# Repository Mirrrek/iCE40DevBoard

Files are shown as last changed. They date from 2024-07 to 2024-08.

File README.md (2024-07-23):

# iCE40 DevBoard

This project was made as part of [Hack Club Arcade 2024](https://hackclub.com/arcade/).

## Warning

The current board design has not been tested and has known mistakes:
1. **R3 is placed on the wrong side of the level shifter.** Do not solder R3 on and add a 1k pullup to 3v3 on the FPGA's _CDONE_ pin (via TP4).
2. **The FPGA's _SPI\_SS_ pin is missing a pullup resistor.** Add a 10k pullup to 3v3 on the FPGA's _SPI\_SS_ pin (via TP9).

These changes will be permanently applied to the design in a future iteration.

## Hardware

All required libraries can be downloaded from [SnapEDA](https://www.snapeda.com/home/).

- **iCE5LP2K-SG48ITR** FPGA
- **10118194-0011LF** USB micro connector
- **AMS1117** 3.3V and 1.2V voltage regulators
- **AT25DN011** SPI flash
- **CCBTLV3257MPWREP** multiplexer
- **TXS0108EPWR** level shifter

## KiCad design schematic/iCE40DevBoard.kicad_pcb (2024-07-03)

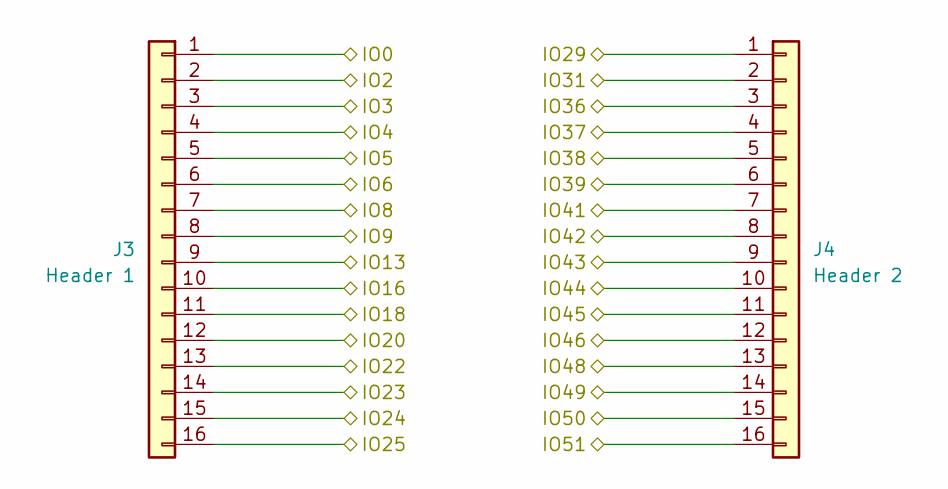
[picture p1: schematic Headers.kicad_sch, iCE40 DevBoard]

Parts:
J3: Header 1; PinHeader_1x16_P2.54mm_Vertical
J4: Header 2; PinHeader_1x16_P2.54mm_Vertical

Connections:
/FPGA/IO0: J3.1; also elsewhere on the board
/FPGA/IO2: J3.2; also elsewhere on the board
/FPGA/IO3: J3.3; also elsewhere on the board
/FPGA/IO4: J3.4; also elsewhere on the board
/FPGA/IO5: J3.5; also elsewhere on the board
/FPGA/IO6: J3.6; also elsewhere on the board
/FPGA/IO8: J3.7; also elsewhere on the board
/FPGA/IO9: J3.8; also elsewhere on the board
/FPGA/IO13: J3.9; also elsewhere on the board
/FPGA/IO16: J3.10; also elsewhere on the board
/FPGA/IO18: J3.11; also elsewhere on the board
/FPGA/IO20: J3.12; also elsewhere on the board
/FPGA/IO22: J3.13; also elsewhere on the board
/FPGA/IO23: J3.14; also elsewhere on the board
/FPGA/IO24: J3.15; also elsewhere on the board
/FPGA/IO25: J3.16; also elsewhere on the board
/FPGA/IO29: J4.1; also elsewhere on the board
/FPGA/IO31: J4.2; also elsewhere on the board
/FPGA/IO36: J4.3; also elsewhere on the board
/FPGA/IO37: J4.4; also elsewhere on the board
/FPGA/IO38: J4.5; also elsewhere on the board
/FPGA/IO39: J4.6; also elsewhere on the board
/FPGA/IO41: J4.7; also elsewhere on the board
/FPGA/IO42: J4.8; also elsewhere on the board
/FPGA/IO43: J4.9; also elsewhere on the board
/FPGA/IO44: J4.10; also elsewhere on the board
/FPGA/IO45: J4.11; also elsewhere on the board
/FPGA/IO46: J4.12; also elsewhere on the board
/FPGA/IO48: J4.13; also elsewhere on the board
/FPGA/IO49: J4.14; also elsewhere on the board
/FPGA/IO50: J4.15; also elsewhere on the board
/FPGA/IO51: J4.16; also elsewhere on the board

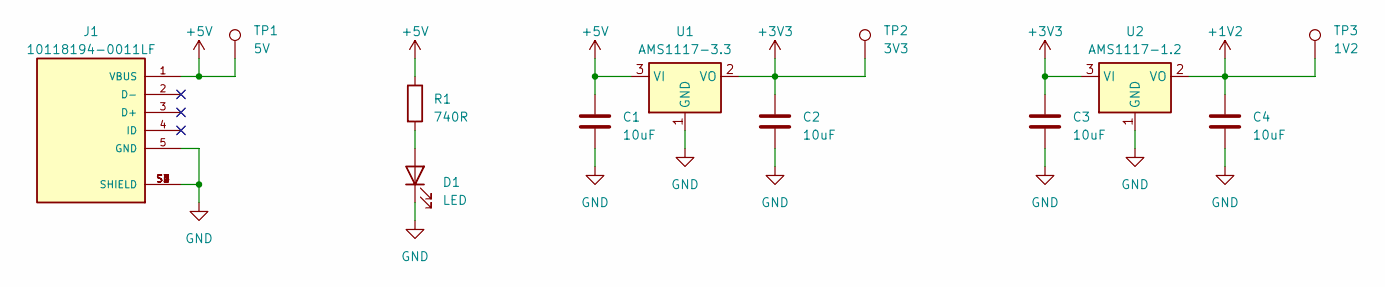
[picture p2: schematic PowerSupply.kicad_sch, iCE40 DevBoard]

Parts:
C1, C2, C3, C4: 10uF; C_0603_1608Metric
D1: LED; LED_0805_2012Metric
J1: 10118194-0011LF; AMPHENOL_10118194-0011LF; PARTREV D
R1: 740R; R_0603_1608Metric
TP1: 5V; TestPoint_Pad_D1.0mm
TP2: 3V3; TestPoint_Pad_D1.0mm
TP3: 1V2; TestPoint_Pad_D1.0mm
U1: AMS1117-3.3; SOT-223-3_TabPin2
U2: AMS1117-1.2; SOT-223-3_TabPin2

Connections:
+1V2: C4.1, TP3.1, U2.2 (VO); also elsewhere on the board
+3V3: C2.1, C3.1, TP2.1, U1.2 (VO), U2.3 (VI); also elsewhere on the board
+5V: C1.1, J1.1 (VBUS), R1.1, TP1.1, U1.3 (VI); also elsewhere on the board
GND: C1.2, C2.2, C3.2, C4.2, D1.1 (K), J1.5 (GND), J1.S1 (SHIELD), J1.S2 (SHIELD), J1.S3 (SHIELD), J1.S4 (SHIELD), J1.S5 (SHIELD), J1.S6 (SHIELD), U1.1 (GND), U2.1 (GND); also elsewhere on the board
unnamed: D1.2 (A), R1.2

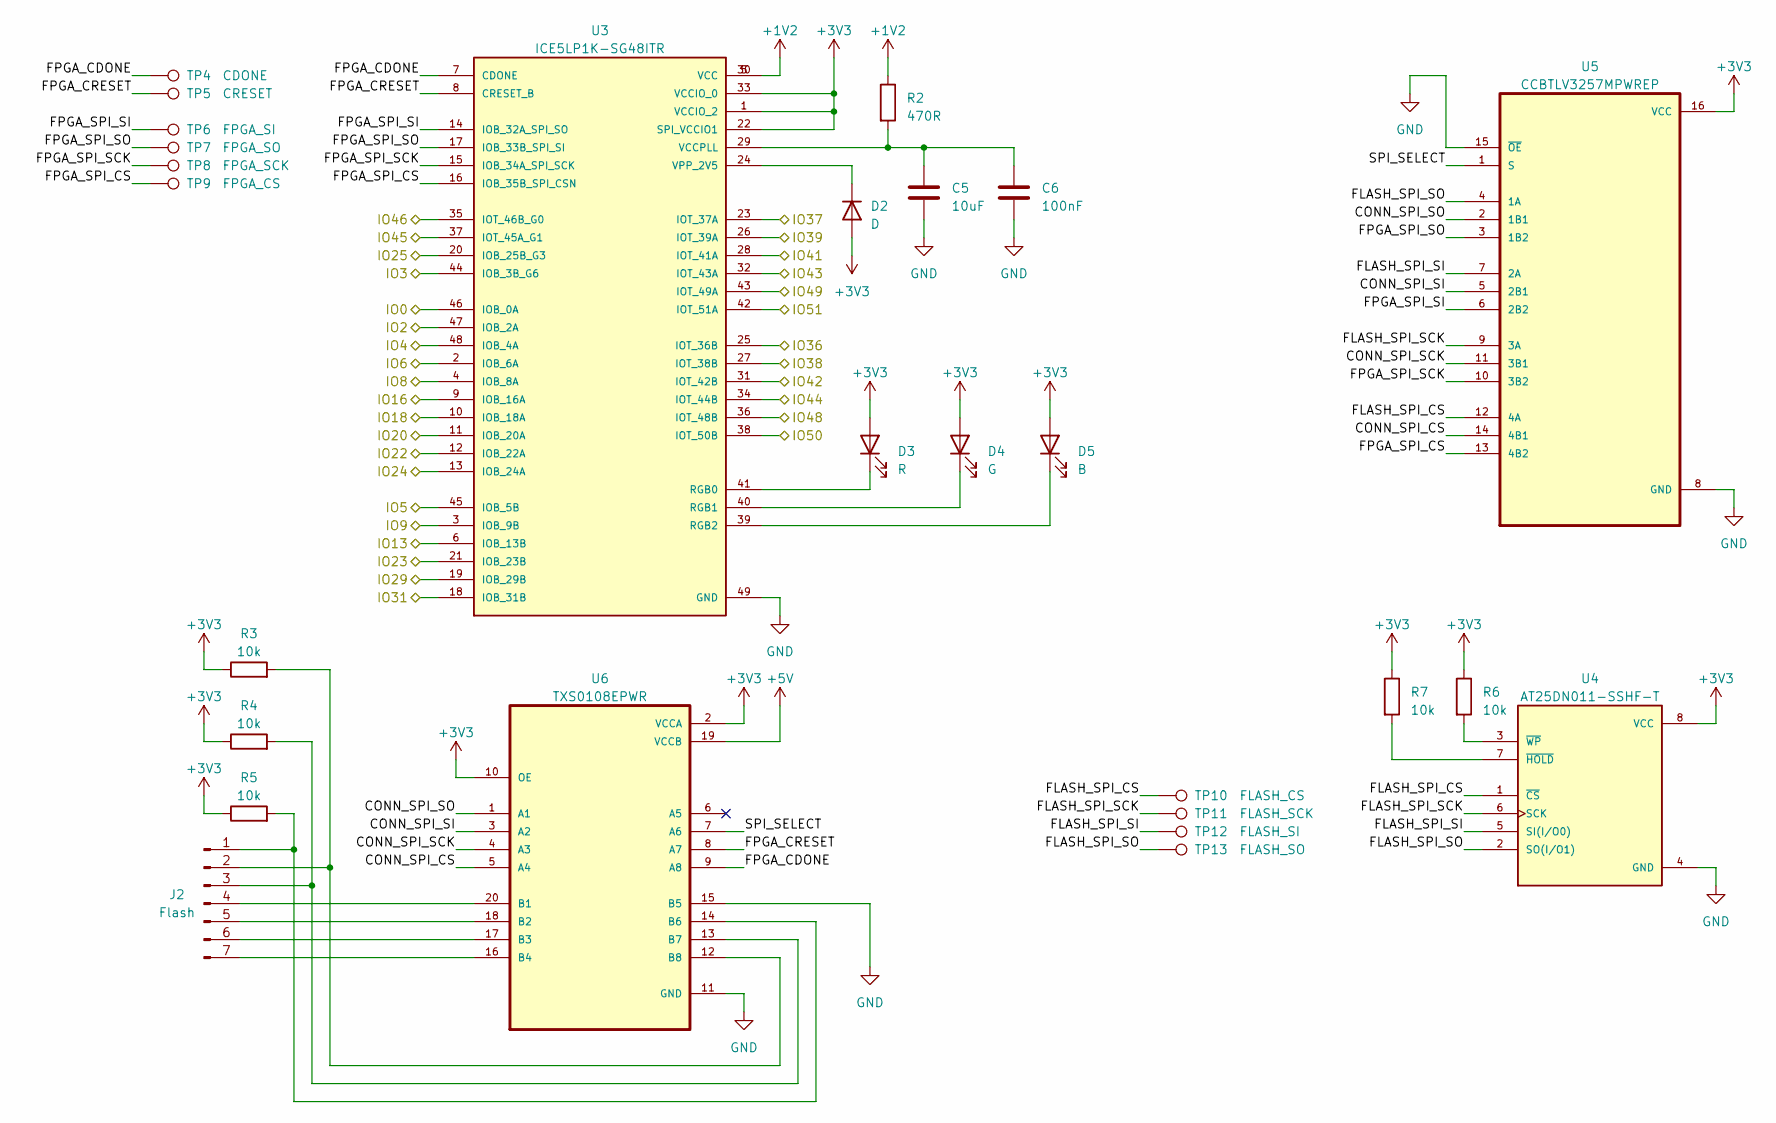
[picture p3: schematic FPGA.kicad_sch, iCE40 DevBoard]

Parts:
C5: 10uF; C_0603_1608Metric
C6: 100nF; C_0603_1608Metric
D2: D; D_0603_1608Metric
D3: R; LED_0805_2012Metric
D4: G; LED_0805_2012Metric
D5: B; LED_0805_2012Metric
J2: Flash; PinHeader_1x07_P2.54mm_Vertical
R2: 470R; R_0603_1608Metric
R3, R4, R5, R6, R7: 10k; R_0603_1608Metric
TP4: CDONE; TestPoint_Pad_D1.0mm
TP5: CRESET; TestPoint_Pad_D1.0mm
TP6: FPGA_SI; TestPoint_Pad_D1.0mm
TP7: FPGA_SO; TestPoint_Pad_D1.0mm
TP8: FPGA_SCK; TestPoint_Pad_D1.0mm
TP9: FPGA_CS; TestPoint_Pad_D1.0mm
TP10: FLASH_CS; TestPoint_Pad_D1.0mm
TP11: FLASH_SCK; TestPoint_Pad_D1.0mm
TP12: FLASH_SI; TestPoint_Pad_D1.0mm
TP13: FLASH_SO; TestPoint_Pad_D1.0mm
U3: ICE5LP1K-SG48ITR; QFN50P700X700X100-49N
U4: AT25DN011-SSHF-T; SOIC127P599X175-8N; PARTREV G
U5: CCBTLV3257MPWREP; SOP65P640X120-16N
U6: TXS0108EPWR; SOP65P640X120-20N

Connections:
+1V2: R2.1, U3.5 (VCC), U3.30 (VCC); also elsewhere on the board
+3V3: D2.2 (A), D3.2 (A), D4.2 (A), D5.2 (A), R3.1, R4.1, R5.1, R6.1, R7.1, U3.1 (VCCIO_2), U3.22 (SPI_VCCIO1), U3.33 (VCCIO_0), U4.8 (VCC), U5.16 (VCC), U6.2 (VCCA), U6.10 (OE); also elsewhere on the board
+5V: U6.19 (VCCB); also elsewhere on the board
/FPGA/CONN_SPI_CS: U5.14 (4B1), U6.5 (A4)
/FPGA/CONN_SPI_SCK: U5.11 (3B1), U6.4 (A3)
/FPGA/CONN_SPI_SI: U5.5 (2B1), U6.3 (A2)
/FPGA/CONN_SPI_SO: U5.2 (1B1), U6.1 (A1)
/FPGA/FLASH_SPI_CS: TP10.1, U4.1 (~CS), U5.12 (4A)
/FPGA/FLASH_SPI_SCK: TP11.1, U4.6 (SCK), U5.9 (3A)
/FPGA/FLASH_SPI_SI: TP12.1, U4.5 (SI(I/O0)), U5.7 (2A)
/FPGA/FLASH_SPI_SO: TP13.1, U4.2 (SO(I/O1)), U5.4 (1A)
/FPGA/FPGA_CDONE: TP4.1, U3.7 (CDONE), U6.9 (A8)
/FPGA/FPGA_CRESET: TP5.1, U3.8 (CRESET_B), U6.8 (A7)
/FPGA/FPGA_SPI_CS: TP9.1, U3.16 (IOB_35B_SPI_CSN), U5.13 (4B2)
/FPGA/FPGA_SPI_SCK: TP8.1, U3.15 (IOB_34A_SPI_SCK), U5.10 (3B2)
/FPGA/FPGA_SPI_SI: TP6.1, U3.14 (IOB_32A_SPI_SO), U5.6 (2B2)
/FPGA/FPGA_SPI_SO: TP7.1, U3.17 (IOB_33B_SPI_SI), U5.3 (1B2)
/FPGA/IO0: U3.46 (IOB_0A); also elsewhere on the board
/FPGA/IO2: U3.47 (IOB_2A); also elsewhere on the board
/FPGA/IO3: U3.44 (IOB_3B_G6); also elsewhere on the board
/FPGA/IO4: U3.48 (IOB_4A); also elsewhere on the board
/FPGA/IO5: U3.45 (IOB_5B); also elsewhere on the board
/FPGA/IO6: U3.2 (IOB_6A); also elsewhere on the board
/FPGA/IO8: U3.4 (IOB_8A); also elsewhere on the board
/FPGA/IO9: U3.3 (IOB_9B); also elsewhere on the board
/FPGA/IO13: U3.6 (IOB_13B); also elsewhere on the board
/FPGA/IO16: U3.9 (IOB_16A); also elsewhere on the board
/FPGA/IO18: U3.10 (IOB_18A); also elsewhere on the board
/FPGA/IO20: U3.11 (IOB_20A); also elsewhere on the board
/FPGA/IO22: U3.12 (IOB_22A); also elsewhere on the board
/FPGA/IO23: U3.21 (IOB_23B); also elsewhere on the board
/FPGA/IO24: U3.13 (IOB_24A); also elsewhere on the board
/FPGA/IO25: U3.20 (IOB_25B_G3); also elsewhere on the board
/FPGA/IO29: U3.19 (IOB_29B); also elsewhere on the board
/FPGA/IO31: U3.18 (IOB_31B); also elsewhere on the board
/FPGA/IO36: U3.25 (IOT_36B); also elsewhere on the board
/FPGA/IO37: U3.23 (IOT_37A); also elsewhere on the board
/FPGA/IO38: U3.27 (IOT_38B); also elsewhere on the board
/FPGA/IO39: U3.26 (IOT_39A); also elsewhere on the board
/FPGA/IO41: U3.28 (IOT_41A); also elsewhere on the board
/FPGA/IO42: U3.31 (IOT_42B); also elsewhere on the board
/FPGA/IO43: U3.32 (IOT_43A); also elsewhere on the board
/FPGA/IO44: U3.34 (IOT_44B); also elsewhere on the board
/FPGA/IO45: U3.37 (IOT_45A_G1); also elsewhere on the board
/FPGA/IO46: U3.35 (IOT_46B_G0); also elsewhere on the board
/FPGA/IO48: U3.36 (IOT_48B); also elsewhere on the board
/FPGA/IO49: U3.43 (IOT_49A); also elsewhere on the board
/FPGA/IO50: U3.38 (IOT_50B); also elsewhere on the board
/FPGA/IO51: U3.42 (IOT_51A); also elsewhere on the board
/FPGA/SPI_SELECT: U5.1 (S), U6.7 (A6)
GND: C5.2, C6.2, U3.49 (GND), U4.4 (GND), U5.8 (GND), U5.15 (~OE), U6.11 (GND), U6.15 (B5); also elsewhere on the board
unnamed: D2.1 (K), U3.24 (VPP_2V5)
unnamed: D3.1 (K), U3.41 (RGB0)
unnamed: D4.1 (K), U3.40 (RGB1)
unnamed: D5.1 (K), U3.39 (RGB2)
unnamed: J2.1, R5.2, U6.14 (B6)
unnamed: J2.2, R3.2, U6.12 (B8)
unnamed: J2.3, R4.2, U6.13 (B7)
unnamed: J2.4, U6.20 (B1)
unnamed: J2.5, U6.18 (B2)
unnamed: J2.6, U6.17 (B3)
unnamed: J2.7, U6.16 (B4)
unnamed: C5.1, C6.1, R2.2, U3.29 (VCCPLL)
unnamed: R7.2, U4.7 (~HOLD)
unnamed: R6.2, U4.3 (~WP)

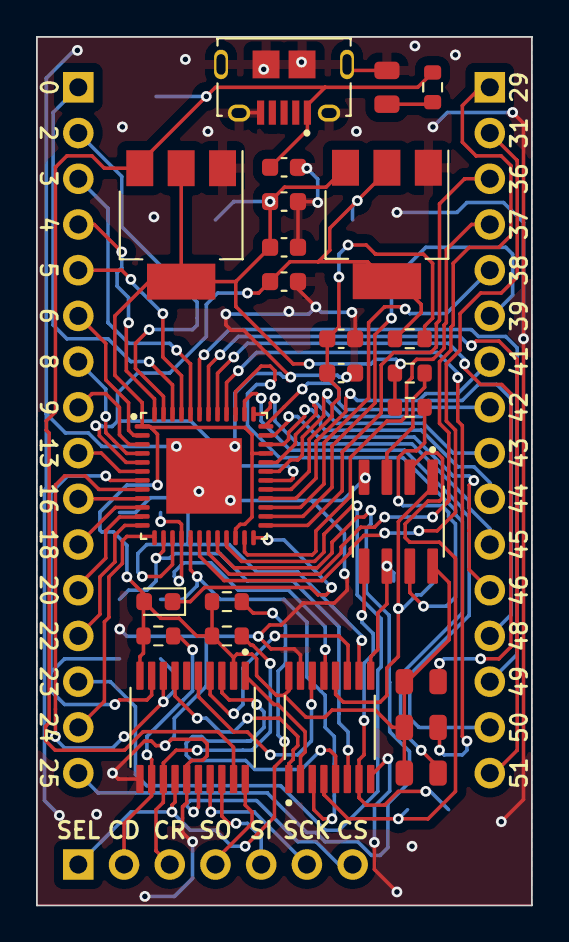
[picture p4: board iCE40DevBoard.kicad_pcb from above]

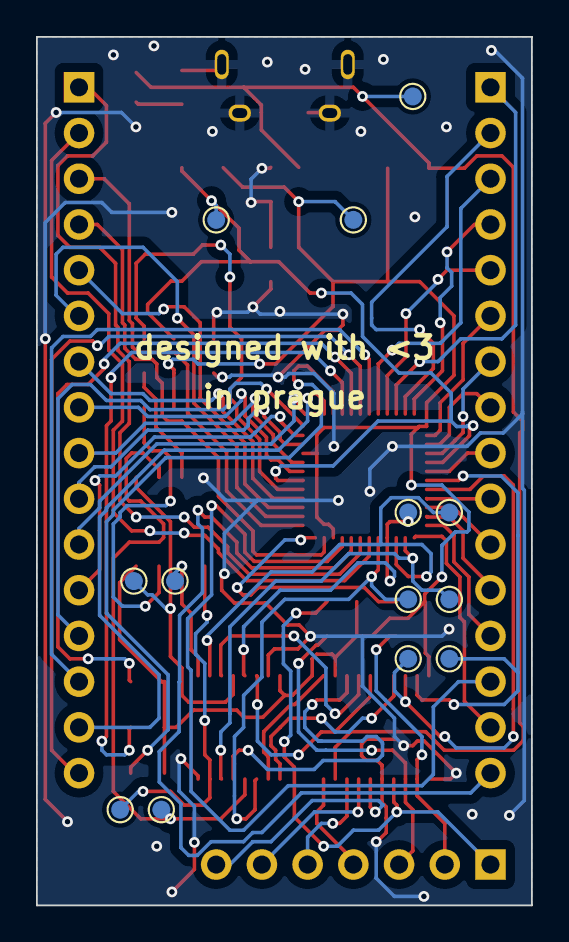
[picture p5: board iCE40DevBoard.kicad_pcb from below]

Board: 2 copper layers, 27.5 x 48.2 mm, 41 parts (13 on the bottom side), 66 nets.

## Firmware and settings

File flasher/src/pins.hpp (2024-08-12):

#ifndef PINS_HPP
#define PINS_HPP

#include <Arduino.h>

#define PIN_SEL 2   // SPI port select
#define PIN_CD 3    // Configuration done
#define PIN_CR 4    // Configuration reset
#define PIN_SO 12   // SPI MISO
#define PIN_SI 11   // SPI MOSI
#define PIN_SCK 13  // SPI clock
#define PIN_CS 10   // SPI chip select

#endif

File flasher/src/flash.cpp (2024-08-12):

#include "flash.hpp"
#include "pins.hpp"
#include <SPI.h>

static void (*_onStatusChange)(bool) = 0;

void onStatusChangeInterrupt() {
    _onStatusChange(digitalRead(PIN_CD) == HIGH);
}

bool waitForReady() {
    SPI.beginTransaction(SPISettings(1000000, MSBFIRST, SPI_MODE0));
    digitalWrite(PIN_CS, LOW);
    SPI.transfer(0x05);
    uint16_t status = 1;
    while (status & 0b1) {
        status = SPI.transfer16(0);
        if (status & 0b100000) {
            digitalWrite(PIN_CS, HIGH);
            SPI.endTransaction();
            return false;
        }
        delayMicroseconds(1);
    }
    digitalWrite(PIN_CS, HIGH);
    SPI.endTransaction();
    delayMicroseconds(1);
    return true;
}

void writeEnable() {
    SPI.beginTransaction(SPISettings(1000000, MSBFIRST, SPI_MODE0));
    digitalWrite(PIN_CS, LOW);
    SPI.transfer(0x06);
    digitalWrite(PIN_CS, HIGH);
    SPI.endTransaction();
    waitForReady();
}

void Flash::begin(void (*onStatusChange)(bool)) {
    _onStatusChange = onStatusChange;
    attachInterrupt(digitalPinToInterrupt(PIN_CD), onStatusChangeInterrupt, CHANGE);
    pinMode(PIN_SEL, OUTPUT);
    pinMode(PIN_CD, INPUT);
    pinMode(PIN_CR, OUTPUT);
    pinMode(PIN_CS, OUTPUT);
    digitalWrite(PIN_SEL, HIGH);
    digitalWrite(PIN_CR, HIGH);
    digitalWrite(PIN_CS, HIGH);
    SPI.begin();
}

void Flash::end() {
    SPI.end();
}

void Flash::enable() {
    digitalWrite(PIN_CR, LOW);
    digitalWrite(PIN_SEL, LOW);

    writeEnable();
    SPI.beginTransaction(SPISettings(1000000, MSBFIRST, SPI_MODE0));
    digitalWrite(PIN_CS, LOW);
    SPI.transfer(0x60);
    digitalWrite(PIN_CS, HIGH);
    SPI.endTransaction();
    waitForReady();
}

void Flash::disable() {
    digitalWrite(PIN_SEL, HIGH);
    digitalWrite(PIN_CR, HIGH);
}

bool Flash::writeChunk(uint16_t chunkAddress, uint8_t* data) {
    writeEnable();
    SPI.beginTransaction(SPISettings(1000000, MSBFIRST, SPI_MODE0));
    digitalWrite(PIN_CS, LOW);
    SPI.transfer(0x02);
    SPI.transfer((chunkAddress >> 8) & 0xff);
    SPI.transfer(chunkAddress & 0xff);
    SPI.transfer(0);
    for (int i = 0; i < 256; i++) {
        SPI.transfer(data[i]);
    }
    digitalWrite(PIN_CS, HIGH);
    SPI.endTransaction();
    return waitForReady();
}

void Flash::readChunk(uint16_t chunkAddress, uint8_t* data) {
    SPI.beginTransaction(SPISettings(1000000, MSBFIRST, SPI_MODE0));
    digitalWrite(PIN_CS, LOW);
    SPI.transfer(0x03);
    SPI.transfer((chunkAddress >> 8) & 0xff);
    SPI.transfer(chunkAddress & 0xff);
    SPI.transfer(0);
    for (int i = 0; i < 256; i++) {
        data[i] = SPI.transfer(0);
    }
    digitalWrite(PIN_CS, HIGH);
    SPI.endTransaction();
}

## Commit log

2024-07-02 Initialize development environment
    [iCE40DevBoard.kicad_pcb, iCE40DevBoard.kicad_sch]
2024-07-02 Setup schematic
    [FPGA.kicad_sch, Headers.kicad_sch, PowerSupply.kicad_sch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]
2024-07-02 Create power supply schematic
    [PowerSupply.kicad_sch]
2024-07-02 Create FPGA schematic
    [FPGA.kicad_sch, Headers.kicad_sch]
2024-07-02 Connect FPGA to headers
    [PowerSupply.kicad_sch, iCE40DevBoard.kicad_sch]
2024-07-02 Add level shifters to SPI lines
    [FPGA.kicad_sch, PowerSupply.kicad_sch]
2024-07-02 Add testpoints to SPI lines
    [FPGA.kicad_sch, PowerSupply.kicad_sch, iCE40DevBoard.kicad_sch]
2024-07-02 Add RGB LEDs to schematic
    [FPGA.kicad_sch]
2024-07-03 Update flash header schematic
    [FPGA.kicad_sch, Headers.kicad_sch, PowerSupply.kicad_sch]
2024-07-03 Design and trace PCB
    [iCE40DevBoard.kicad_pcb]
2024-07-03 Generate gerber files
    [iCE40DevBoard-B_Cu.gbl, iCE40DevBoard-B_Mask.gbs, iCE40DevBoard-B_Paste.gbp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]
2024-08-12 Fix flash address setting
    [flash.cpp]
